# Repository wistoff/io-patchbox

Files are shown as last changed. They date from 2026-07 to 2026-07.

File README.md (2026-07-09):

# I/O Patchbox

A 3-channel sensor-to-actor controller designed for **Manou Wistoff**'s approach to **phygitale Kunsttherapie**, part of her master thesis at [Alanus Kunsthochschule](https://www.alanus.edu).

Building on the concept of phygitale Kunsttherapie, the I/O Patchbox makes the digital tangible by bringing interactive electronics into the physical space. Interactive electronic components become *material* in the art therapy process, just like clay, paint, or fabric. Through process-oriented creating (Tinkering), clients combine classical crafting materials with sensors and actors connected through the I/O Patchbox, resulting in interactive artworks.

The I/O Patchbox is built on an ESP32-S3 Mini with a custom carrier PCB. Each channel auto-detects its sensor type at boot (ultrasonic HC-SR04 or capacitive touch) and drives an output (LED, motor) proportionally via PWM through a low-side NPN transistor stage.

<p align="center">
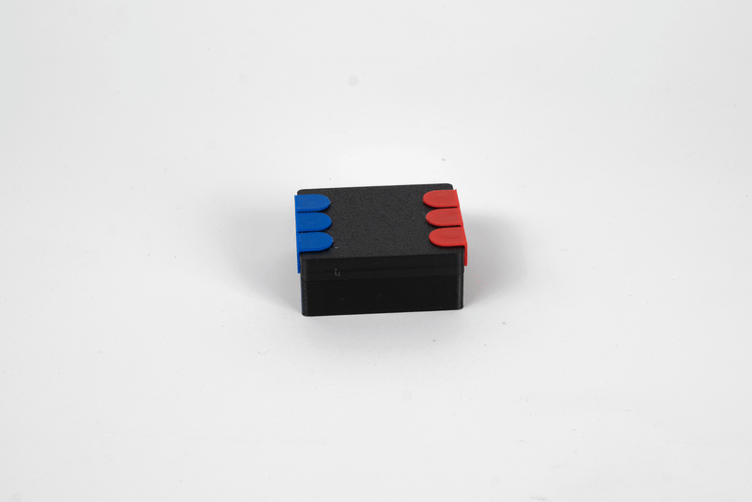
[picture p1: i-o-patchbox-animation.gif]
I/O Patchbox in action
  
</p>

<p align="center">
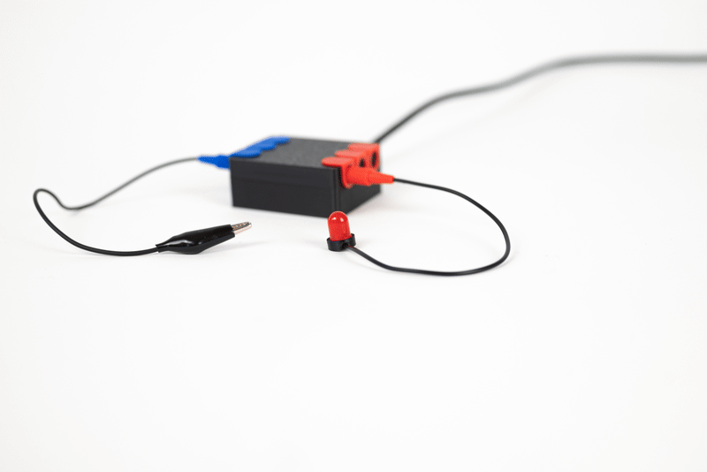
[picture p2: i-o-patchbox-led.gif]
LED output
  
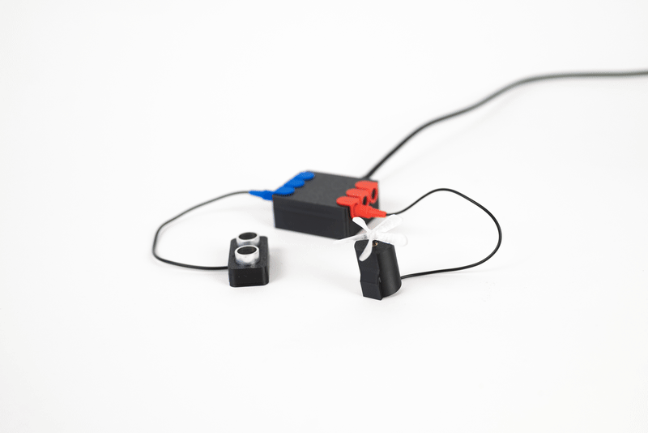
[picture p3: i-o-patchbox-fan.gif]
Fan output
  
</p>

## How it works

- **3 sensor inputs** (TRRS jacks) carrying power, trigger, echo, and ground
- **3 actor outputs** (TRRS jacks) with 5V PWM low-side switch (2N2222 + flyback diode), load adapted in cable
- **Mode switch** to enable/disable all outputs and trigger recalibration
- **Auto-detect** probes each channel for ultrasonic echoes and falls back to touch if none are found
- Ultrasonic: brightness inversely proportional to distance (0-60 cm)
- Touch: brightness proportional to capacitive contact, with adaptive baseline and asymmetric smoothing

## Project structure

```
i-o-patchbox/
├── firmware/
│   ├── esp32s3-mini/            # current target (LOLIN ESP32-S3 Mini)
│   │   ├── src/main.cpp
│   │   ├── platformio.ini
│   │   └── PINOUT.md
│   └── esp32-wroom-dev-board/   # earlier prototype (ESP32 WROOM DevKit)
│       ├── src/main.cpp
│       ├── platformio.ini
│       └── PINOUT.md
├── hardware/                    # KiCad 10 PCB project
│   ├── pcb.kicad_sch             # schematic
│   ├── pcb.kicad_pcb             # board layout (single-sided, home-etched)
│   ├── pcb.kicad_pro             # project file
│   ├── libs/PJ-320A/             # TRRS jack symbol + footprint library
│   ├── gerber/                   # fabrication outputs
│   ├── exports/                  # SVG renders, drill maps
│   ├── backups/                  # KiCad auto-backups
│   └── schaltplan.pdf            # schematic export
└── enclosure/                   # 3D-printable cases (OBJ)
    ├── cable-plug.obj            # cable strain relief (used by all sensors and actors)
    ├── patchbox/                 # main device enclosure
    │   ├── top.obj
    │   ├── bottom.obj
    │   └── indicator.obj
    ├── sensors/                  # sensor housings
    │   ├── ultrasonic-top.obj
    │   └── ultrasonic-bottom.obj
    └── actors/                   # actor housings
        ├── dc-motor-top.obj
        ├── dc-motor-bottom.obj
        ├── vibration-motor-top.obj
        ├── vibration-motor-bottom.obj
        └── led.obj
```

## Pin assignment (ESP32-S3 Mini)

| Channel | Trigger / Touch | Echo  | Actor |
|---|---|---|---|
| 1 | GP1 | GP7 | GP10  |
| 2 | GP2 | GP8 | GP11  |
| 3 | GP3 | GP9 | GP12  |
| Switch  | - | - | GP13  |

## Sensors

All sensors connect via 4-pole TRRS jacks (PJ-320D). Wiring: Tip = +5V, Ring1 = TRIG, Ring2 = ECHO, Sleeve = GND.

Each channel auto-detects its sensor type at startup by probing for ultrasonic echoes. If none are found, it falls back to capacitive touch.

| Type | Part | How it works |
|---|---|---|
| **Ultrasonic** | HC-SR04 | Distance sensor (2-60 cm). All 4 TRRS conductors used. Output brightness is inversely proportional to distance. |
| **Capacitive touch** | Bare wire / crocodile cable | Connects to the ECHO pin (Ring2) only. Touch value increases on contact (ESP32-S3 behavior). Adaptive baseline with asymmetric smoothing. Slow ramp-up absorbs motor-stop noise while fast ramp-down keeps release responsive. Recalibrates each time the switch is toggled on. |

## Actors

All actors connect via TRRS jacks. Wiring: Tip = +5V (always on), Sleeve = transistor collector (PWM-switched ground). Ring1/Ring2 unused.

The board provides a generic 5V PWM low-side driver per channel (2N2222 + 330R base resistor + 1N4007 flyback diode). The load type is adapted in the device cable with a series resistor, so no board changes are needed to swap between LEDs and motors.

| Load | Cable resistor | Notes |
|---|---|---|
| **LED** (red/yellow) | 150R series | ~20 mA at 5V, polarity matters (anode to Tip) |
| **LED** (green/blue/white) | 100R series | Higher Vf, ~18 mA |
| **5V motor** | none | Direct connection, bare cable |
| **3V vibration motor** | none | Runs off 5V directly, no series resistor |

PWM runs at 25 kHz (inaudible for motors), 8-bit resolution (0-255).

## Building firmware

Requires [PlatformIO](https://platformio.org/).

```sh
cd firmware/esp32s3-mini
pio run -t upload
pio device monitor
```

## Hardware

Single-sided carrier PCB designed in KiCad 10 for home etching (toner transfer). All copper on F.Cu, SMD TRRS jacks, THT passives soldered from the top side.

<p align="center">
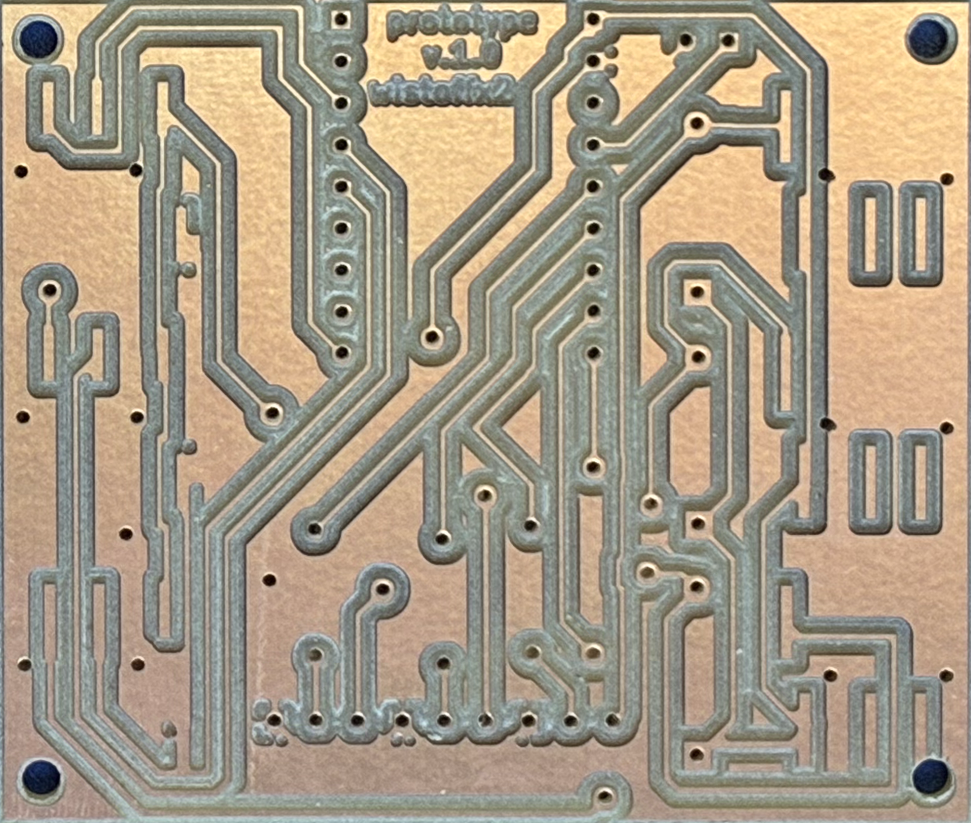
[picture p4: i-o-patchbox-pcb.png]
Etched PCB
  
</p>

Key components: 3x PJ-320D TRRS jacks (sensor), 3x PJ-320D (actor), 3x 2N2222 NPN transistors, 3x 330R base resistors, 3x 1N4007 flyback diodes.

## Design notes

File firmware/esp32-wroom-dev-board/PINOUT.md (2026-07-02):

# ESP32 WROOM DevKit Pinout

```
                          ┌───────────┐
                          │  USB/UART │
                          ├───────────┤
                 3.3V  ──┤           ├──  VIN
                  GND  ──┤           ├──  GND
Sensor 1 TRIG / Touch →  D15  ──┤           ├──  D13
                          D2   ──┤           ├──  D12
Sensor 2 TRIG / Touch →  D4   ──┤           ├──  D14
    Sensor 1 ECHO  →  D16  ──┤           ├──  D27  ← Sensor 3 TRIG / Touch
    Sensor 2 ECHO  →  D17  ──┤           ├──  D26
    Sensor 3 ECHO  →  D5   ──┤           ├──  D25
        Actor 1  →  D18  ──┤           ├──  D33
        Actor 2  →  D19  ──┤           ├──  D32
        Actor 3  →  D21  ──┤           ├──  D35
              D3 (RX)  ──┤           ├──  D34
              D1 (TX)  ──┤           ├──  D39
      Switch →  D22  ──┤           ├──  D36
                  D23  ──┤           ├──  EN
                          └───────────┘
```

## Channel Assignment

| | Sensor | Sensor | Actor  |
|---|---|---|---|
| | TRIG / Touch | ECHO | LED |
| **1** | D15 (GPIO 15)| D16 | D18 |
| **2** | D4  (GPIO 4) | D17 | D19 |
| **3** | D27 (GPIO 27)| D5 | D21 |

## Wiring per Channel

### Ultrasonic (HC-SR04)
```
HC-SR04 VCC  → 5V
HC-SR04 GND  → GND
HC-SR04 TRIG → TRIG pin
HC-SR04 ECHO → ECHO pin
```

### Touch (wire/cable)
```
Wire → TRIG pin (no other connections needed)
```

Each channel auto-detects the sensor type at boot.
LED anode → LED pin (with resistor), cathode → GND.

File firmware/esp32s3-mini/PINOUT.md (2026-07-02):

# ESP32-S3 Mini Pinout

```
                        ┌───────────┐
                        │  USB-C    │
                        ├───────────┤
                  5V  ──┤           ├──  TX
                 GND  ──┤           ├──  RX
            3V3(OUT)  ──┤           ├──  GP13 ← Switch
Sensor 1 TRIG/Touch → GP1  ──┤           ├──  GP12 ← Actor 3
Sensor 2 TRIG/Touch → GP2  ──┤           ├──  GP11 ← Actor 2
Sensor 3 TRIG/Touch → GP3  ──┤           ├──  GP10 ← Actor 1
                 GP4  ──┤           ├──  GP9  ← Sensor 3 ECHO
                 GP5  ──┤           ├──  GP8  ← Sensor 2 ECHO
                 GP6  ──┤           ├──  GP7  ← Sensor 1 ECHO
                        │           ├──  GP16
                        │           ├──  GP15
                        │           ├──  GP14
                        └───────────┘
```

## Channel Assignment

| | Sensor | Sensor | Actor  |
|---|---|---|---|
| | TRIG / Touch | ECHO | LED |
| **1** | GP1 | GP7 | GP10 |
| **2** | GP2 | GP8 | GP11 |
| **3** | GP3 | GP9 | GP12 |
| **Switch** | - | - | GP13 |

## Wiring per Channel

### Ultrasonic (HC-SR04)
```
HC-SR04 VCC  → 5V
HC-SR04 GND  → GND
HC-SR04 TRIG → TRIG pin
HC-SR04 ECHO → ECHO pin
```

### Touch (wire/cable)
```
Wire → TRIG pin (no other connections needed)
```

### Switch
```
Toggle switch between GP13 and GND
```

Each channel auto-detects the sensor type at boot.
LED anode → LED pin (with resistor), cathode → GND.

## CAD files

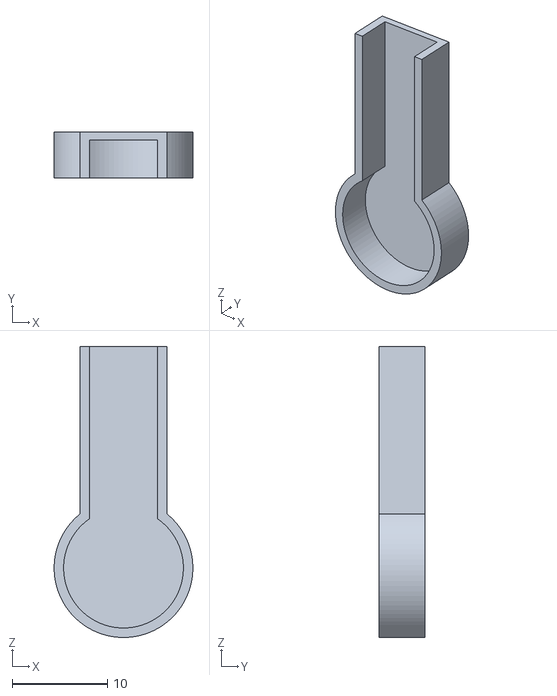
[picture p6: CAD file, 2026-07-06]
enclosure/actors/vibration-motor-top.obj
14.6 x 4.80 x 30.6

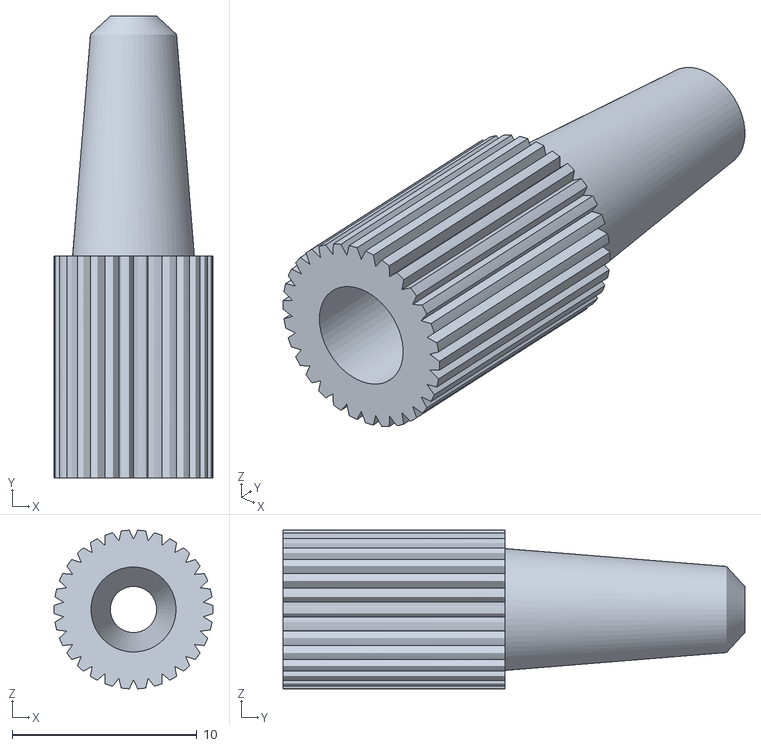
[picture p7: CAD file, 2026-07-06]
enclosure/cable-plug.obj
8.60 x 25.0 x 8.59

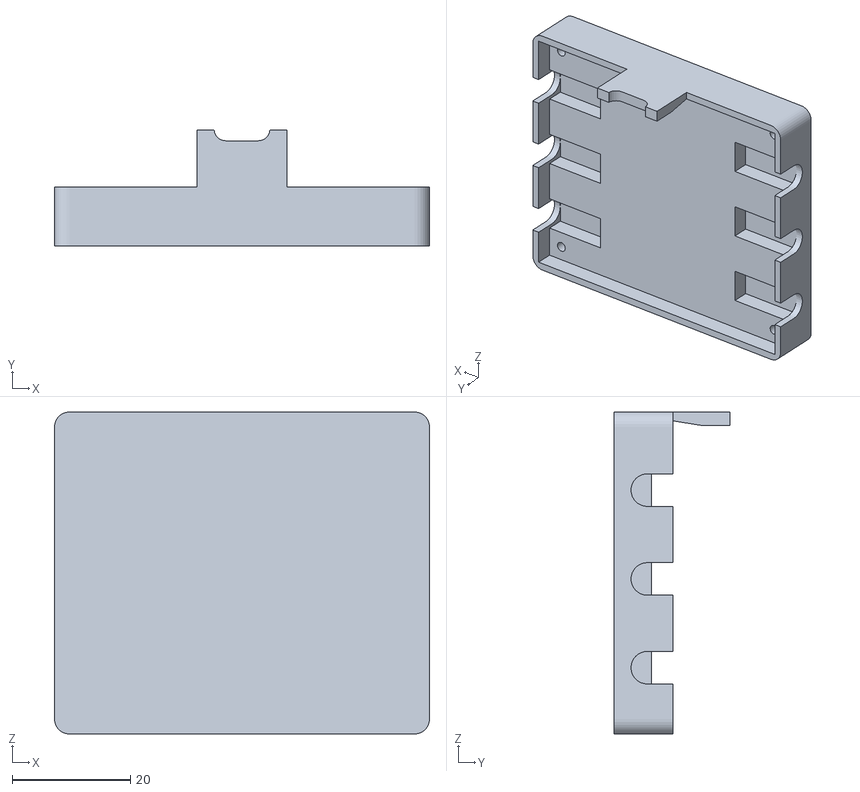
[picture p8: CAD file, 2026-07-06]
enclosure/patchbox/bottom.obj
63.4 x 19.6 x 54.4

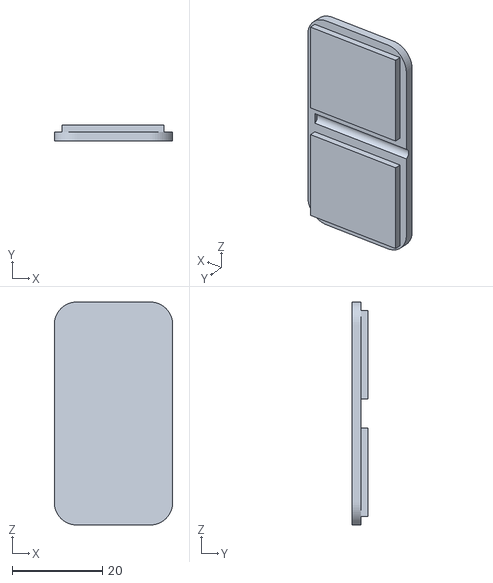
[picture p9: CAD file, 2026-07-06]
enclosure/sensors/ultrasonic-bottom.obj
26.3 x 3.50 x 49.5

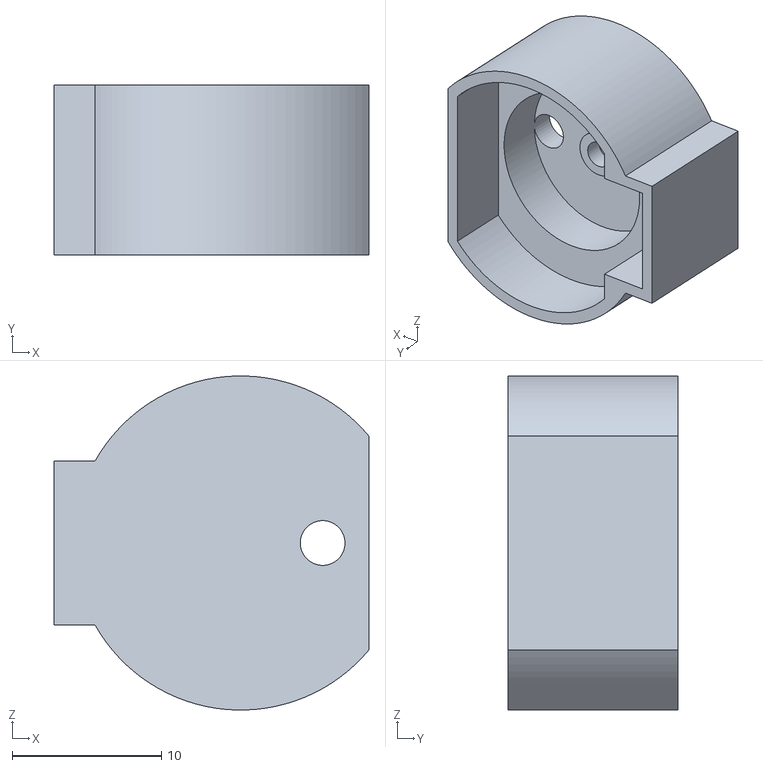
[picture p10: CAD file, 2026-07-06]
enclosure/actors/dc-motor-top.obj
21.1 x 11.4 x 22.4

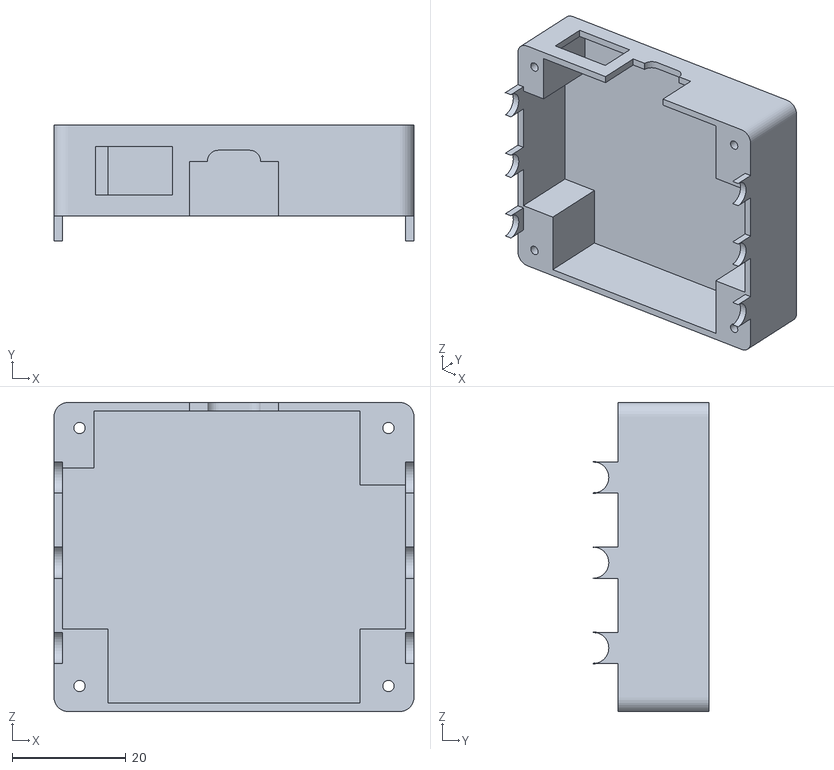
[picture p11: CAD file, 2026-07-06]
enclosure/patchbox/top.obj
63.4 x 20.4 x 54.4

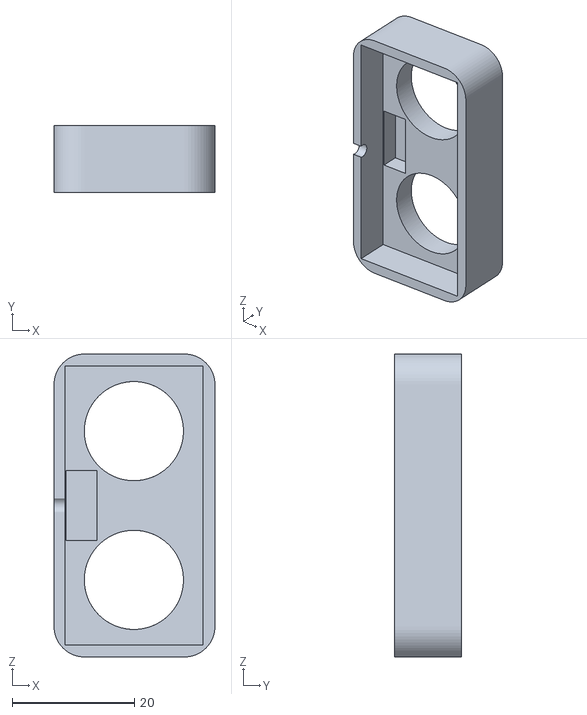
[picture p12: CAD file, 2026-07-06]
enclosure/sensors/ultrasonic-top.obj
26.3 x 11.0 x 49.5

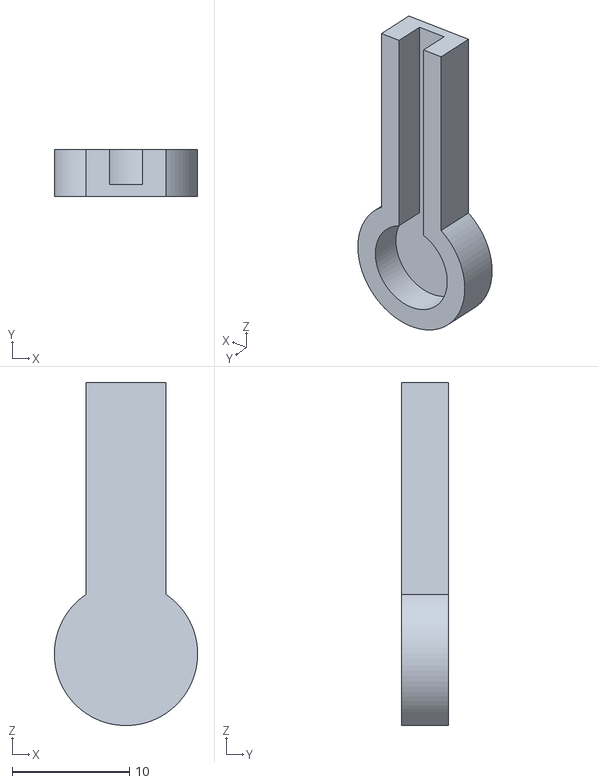
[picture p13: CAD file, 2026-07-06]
enclosure/actors/vibration-motor-bottom.obj
12.2 x 4.00 x 29.2

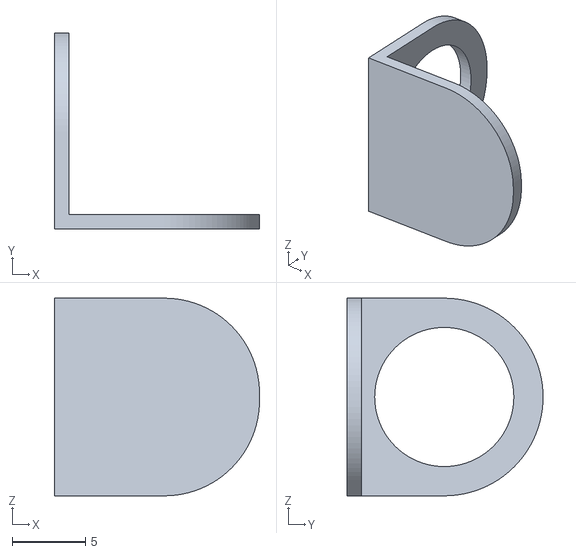
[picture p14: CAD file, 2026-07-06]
enclosure/patchbox/indicator.obj
14.0 x 13.4 x 13.5

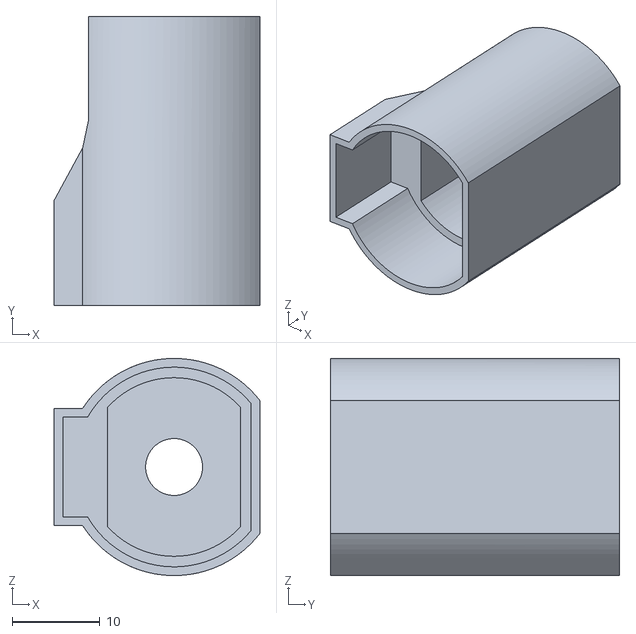
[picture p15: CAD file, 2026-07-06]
enclosure/actors/dc-motor-bottom.obj
23.5 x 33.0 x 24.8

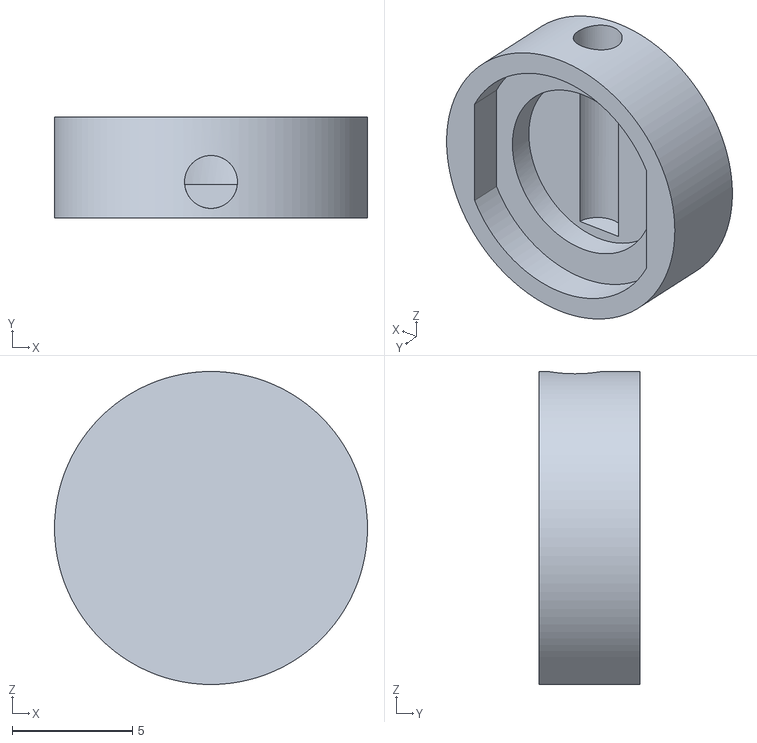
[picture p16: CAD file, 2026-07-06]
enclosure/actors/led.obj
13.0 x 4.20 x 13.0

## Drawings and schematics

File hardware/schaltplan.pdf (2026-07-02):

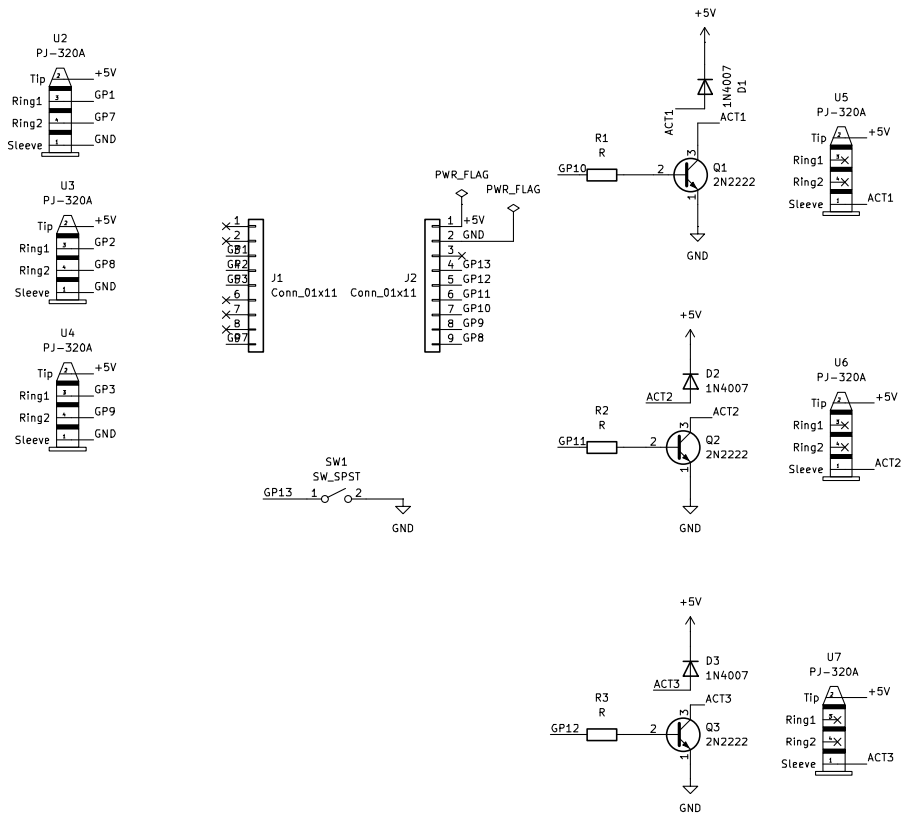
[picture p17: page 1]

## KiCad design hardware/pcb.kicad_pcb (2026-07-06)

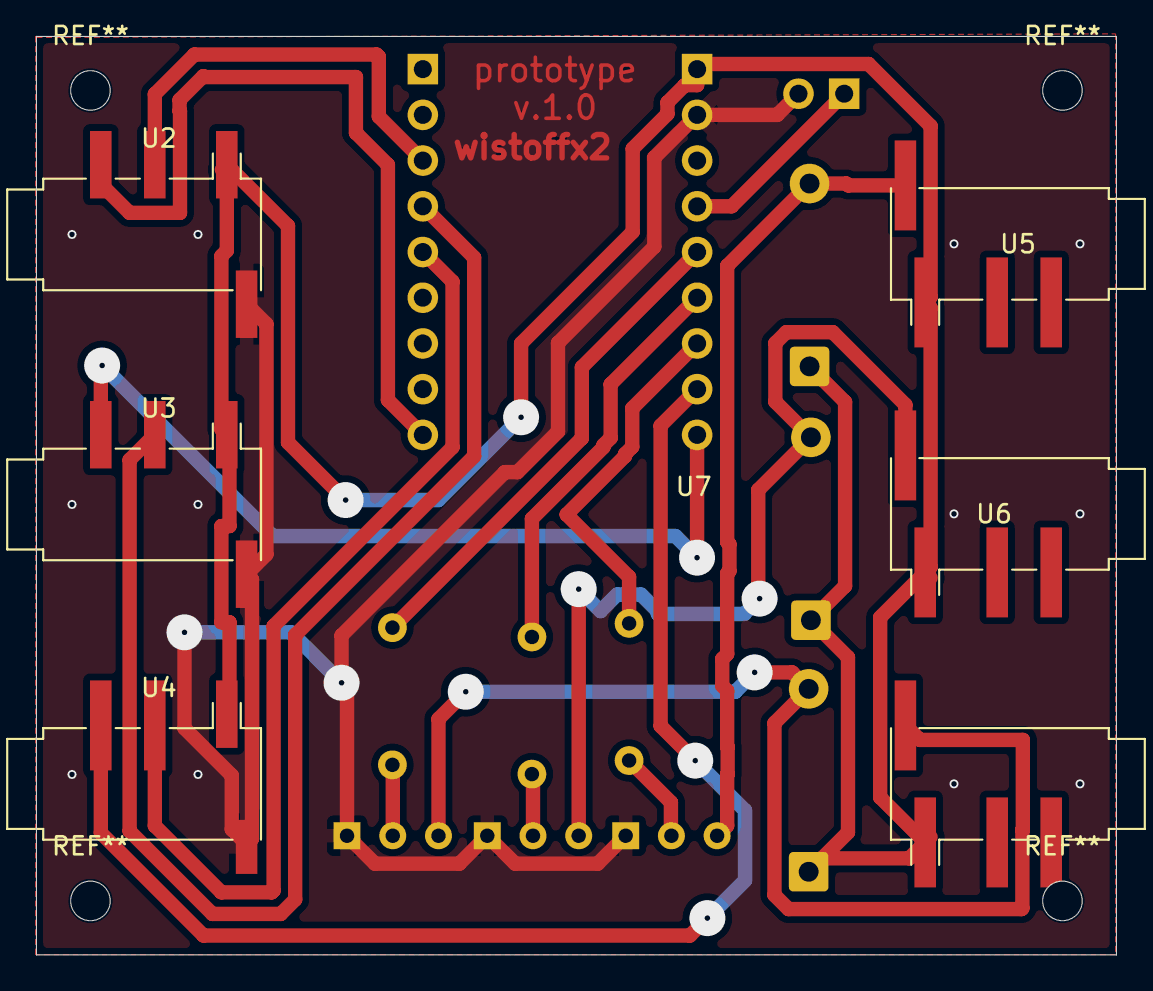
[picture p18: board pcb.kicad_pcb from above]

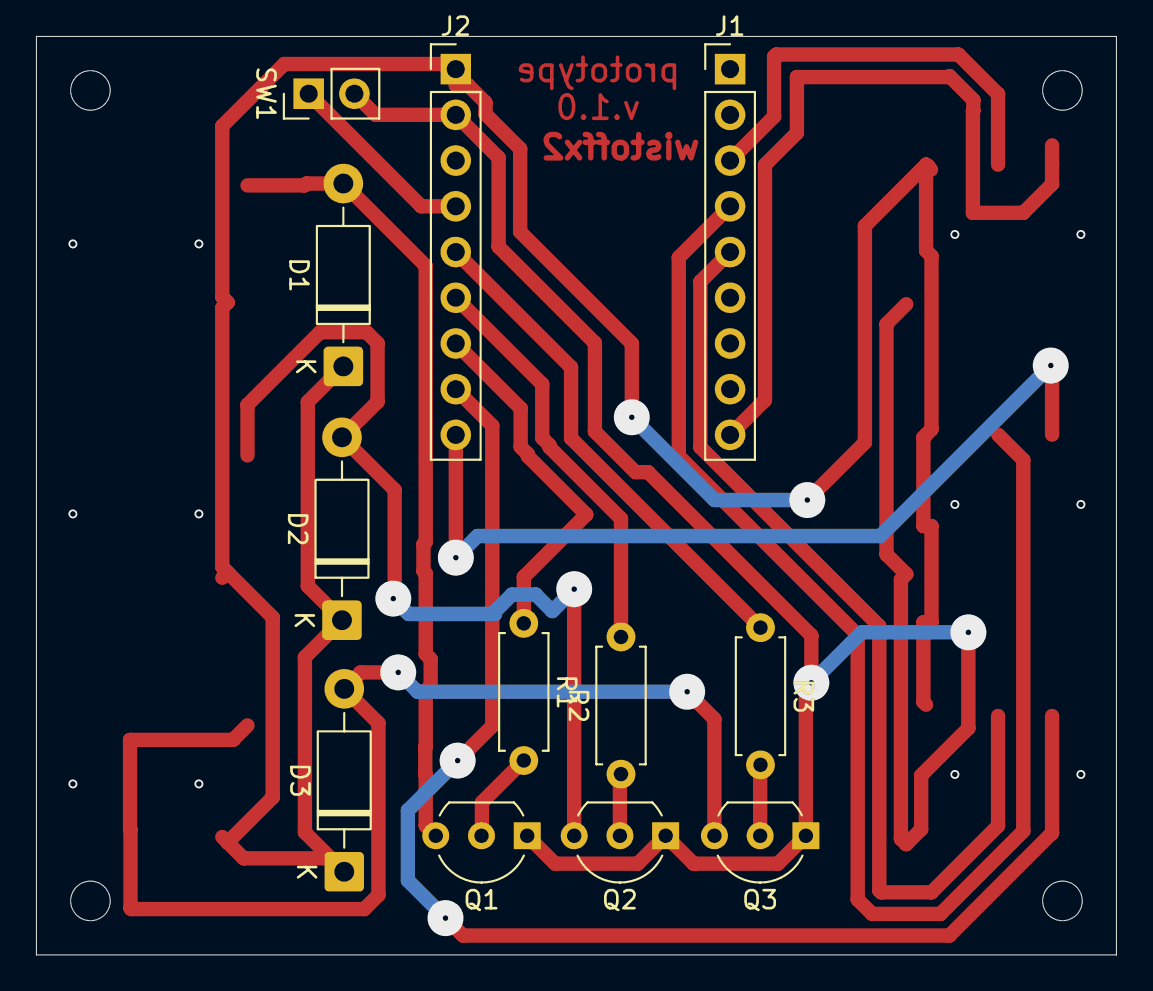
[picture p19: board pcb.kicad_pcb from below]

Board: 2 copper layers, 60.0 x 51.0 mm, 18 parts (12 on the bottom side), 2 nets.

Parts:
D1, D2, D3: 1N4007; D_DO-41_SOD81_P10.16mm_Horizontal
J1, J2: Conn_01x11; PinHeader_1x09_P2.54mm_Vertical
Q1, Q2, Q3: 2N2222; TO-92_Inline_Wide
R1, R2, R3: R; R_Axial_DIN0207_L6.3mm_D2.5mm_P7.62mm_Horizontal
SW1: SW_SPST; PinHeader_1x02_P2.54mm_Vertical
U2, U3, U4, U5, U6, U7: PJ-320A; PJ-320D_SMD_remap

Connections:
+5V: U2.2 (Tip), U3.2 (Tip), U4.2 (Tip), U5.2 (Tip), U6.2 (Tip), U7.2 (Tip)
GND: U2.1 (Sleeve), U3.1 (Sleeve), U4.1 (Sleeve)

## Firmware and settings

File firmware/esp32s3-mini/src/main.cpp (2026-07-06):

#include <Arduino.h>

// Pinout (ESP32-S3 Mini)
// Sensor jack (TRRS): Tip=+5V, Ring1=TRIG, Ring2=ECHO, Sleeve=GND
// Actor jack (TRRS):  Tip=+5V, Sleeve=OUT-, Ring1/Ring2=unused
// Touch connects to ECHO pin (Ring2) via crocodile cable

const int SWITCH_PIN = 13;
const int NUM_CH = 3;
const int TRIG[] = {1, 2, 3};
const int ECHO[] = {7, 8, 9};
const int ACT[]  = {10, 11, 12};

const float MAX_DIST = 60.0;
const int CALIB_SKIP = 10;
const int CALIB_SAMPLES = 40;

bool isTouch[NUM_CH];
int baseline[NUM_CH];
int calibCount[NUM_CH];
float smoothed[NUM_CH];
bool active = false;

float readDist(int ch) {
  digitalWrite(TRIG[ch], LOW);
  delayMicroseconds(2);
  digitalWrite(TRIG[ch], HIGH);
  delayMicroseconds(10);
  digitalWrite(TRIG[ch], LOW);
  return pulseIn(ECHO[ch], HIGH, 30000) * 0.0343 / 2.0;
}

bool detectUltrasonic(int ch) {
  pinMode(TRIG[ch], OUTPUT);
  pinMode(ECHO[ch], INPUT);
  delay(100);
  int hits = 0;
  for (int i = 0; i < 5; i++) {
    float d = readDist(ch);
    Serial.printf("CH%d probe %d: %.1f cm\n", ch, i, d);
    if (d >= 2.0 && d <= 400.0) hits++;
    delay(50);
  }
  return hits >= 3;
}

void blinkAll(int times) {
  for (int i = 0; i < times; i++) {
    for (int ch = 0; ch < NUM_CH; ch++) ledcWrite(ACT[ch], 255);
    delay(150);
    for (int ch = 0; ch < NUM_CH; ch++) ledcWrite(ACT[ch], 0);
    delay(150);
  }
}

void detectAndCalibrate() {
  for (int ch = 0; ch < NUM_CH; ch++) {
    isTouch[ch] = !detectUltrasonic(ch);
    if (isTouch[ch]) pinMode(ECHO[ch], INPUT);
    baseline[ch] = 0;
    calibCount[ch] = 0;
    smoothed[ch] = 0;
    Serial.printf("CH%d: %s\n", ch, isTouch[ch] ? "Touch" : "Ultrasonic");
  }
}

void setup() {
  Serial.begin(115200);
  delay(2000);
  pinMode(SWITCH_PIN, INPUT_PULLUP);
  for (int ch = 0; ch < NUM_CH; ch++)
    ledcAttach(ACT[ch], 25000, 8);
  Serial.println("MANOU ready");
}

void loop() {
  bool switchOn = digitalRead(SWITCH_PIN) == LOW;

  if (switchOn && !active) {
    active = true;
    Serial.println("Switch: ON");
    detectAndCalibrate();
    blinkAll(5);
  } else if (!switchOn && active) {
    active = false;
    Serial.println("Switch: OFF");
    for (int ch = 0; ch < NUM_CH; ch++) ledcWrite(ACT[ch], 0);
  }

  if (!active) { delay(50); return; }

  for (int ch = 0; ch < NUM_CH; ch++) {
    int bright = 0;

    if (isTouch[ch]) {
      int val = touchRead(ECHO[ch]);

      // Calibration: skip warmup, then take min of samples
      if (calibCount[ch] < CALIB_SKIP + CALIB_SAMPLES) {
        calibCount[ch]++;
        if (calibCount[ch] > CALIB_SKIP && (baseline[ch] == 0 || val < baseline[ch]))
          baseline[ch] = val;
        if (calibCount[ch] == CALIB_SKIP + CALIB_SAMPLES)
          Serial.printf("CH%d: baseline=%d\n", ch, baseline[ch]);
        ledcWrite(ACT[ch], 0);
        continue;
      }

      int rise = val - baseline[ch];
      int deadzone = baseline[ch] / 5;

      // Drift baseline when idle
      if (rise < deadzone)
        baseline[ch] += (val - baseline[ch]) / 10;

      if (rise > deadzone)
        bright = constrain(map(rise, deadzone, baseline[ch], 0, 255), 0, 255);

      // Asymmetric smoothing: fast rise, faster fall
      float alpha = (bright > smoothed[ch]) ? 0.5 : 0.7;
      smoothed[ch] += alpha * (bright - smoothed[ch]);
      bright = (int)(smoothed[ch] + 0.5);
    } else {
      float dist = readDist(ch);
      if (dist > 0 && dist <= MAX_DIST)
        bright = 255 - (int)(dist / MAX_DIST * 255);

      smoothed[ch] += 0.6 * (bright - smoothed[ch]);
      bright = (int)(smoothed[ch] + 0.5);
      if (bright < 20) bright = 0;
    }

    ledcWrite(ACT[ch], bright);
  }

  delay(20);
}

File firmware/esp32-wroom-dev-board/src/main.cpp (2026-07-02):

#include <Arduino.h>

// --- PINOUT ---
// Channel 0: TRIG=D15 (Touch3), ECHO=D16, LED=D18
// Channel 1: TRIG=D4  (Touch0), ECHO=D17, LED=D19
// Channel 2: TRIG=D27 (Touch7), ECHO=D5,  LED=D21

const int SWITCH_PIN = 22;
const int NUM_CHANNELS = 3;

const int TRIG_PINS[NUM_CHANNELS] = {15, 4, 27};  // Touch3, Touch0, Touch7 (D27 on VIN side)
const int ECHO_PINS[NUM_CHANNELS] = {16, 17, 5};
const int LED_PINS[NUM_CHANNELS]  = {18, 19, 21};

const int PWM_FREQ = 5000;
const int PWM_RES = 8;

const float MAX_DIST_CM = 60.0;

bool useTouch[NUM_CHANNELS] = {false, false, false};
int touchBaseline[NUM_CHANNELS] = {0, 0, 0};
bool active = false;

float readDistanceCm(int ch) {
  digitalWrite(TRIG_PINS[ch], LOW);
  delayMicroseconds(2);
  digitalWrite(TRIG_PINS[ch], HIGH);
  delayMicroseconds(10);
  digitalWrite(TRIG_PINS[ch], LOW);
  long duration = pulseIn(ECHO_PINS[ch], HIGH, 30000);
  return duration * 0.0343 / 2.0;
}

bool detectUltrasonic(int ch) {
  pinMode(TRIG_PINS[ch], OUTPUT);
  pinMode(ECHO_PINS[ch], INPUT);
  for (int i = 0; i < 5; i++) {
    if (readDistanceCm(ch) > 0) return true;
    delay(50);
  }
  return false;
}

void blinkAll(int times) {
  for (int i = 0; i < times; i++) {
    for (int ch = 0; ch < NUM_CHANNELS; ch++) ledcWrite(LED_PINS[ch], 255);
    delay(150);
    for (int ch = 0; ch < NUM_CHANNELS; ch++) ledcWrite(LED_PINS[ch], 0);
    delay(150);
  }
}

void setup() {
  Serial.begin(115200);
  pinMode(SWITCH_PIN, INPUT_PULLUP);

  for (int ch = 0; ch < NUM_CHANNELS; ch++) {
    ledcAttach(LED_PINS[ch], PWM_FREQ, PWM_RES);

    if (detectUltrasonic(ch)) {
      useTouch[ch] = false;
      Serial.printf("CH%d: Ultrasonic (TRIG=%d, ECHO=%d, LED=%d)\n",
                     ch, TRIG_PINS[ch], ECHO_PINS[ch], LED_PINS[ch]);
    } else {
      useTouch[ch] = true;
      pinMode(TRIG_PINS[ch], INPUT);
      int sum = 0;
      for (int i = 0; i < 10; i++) {
        sum += touchRead(TRIG_PINS[ch]);
        delay(20);
      }
      touchBaseline[ch] = sum / 10;
      Serial.printf("CH%d: Touch (GPIO %d, baseline=%d, LED=%d)\n",
                     ch, TRIG_PINS[ch], touchBaseline[ch], LED_PINS[ch]);
    }
  }
}

void loop() {
  bool switchOn = digitalRead(SWITCH_PIN) == LOW;

  if (switchOn && !active) {
    active = true;
    Serial.println("Switch: ON");
    blinkAll(5);
  } else if (!switchOn && active) {
    active = false;
    Serial.println("Switch: OFF");
    for (int ch = 0; ch < NUM_CHANNELS; ch++) ledcWrite(LED_PINS[ch], 0);
  }

  if (!active) {
    delay(50);
    return;
  }

  for (int ch = 0; ch < NUM_CHANNELS; ch++) {
    int brightness = 0;

    if (useTouch[ch]) {
      int val = touchRead(TRIG_PINS[ch]);
      int drop = touchBaseline[ch] - val;
      if (drop > 0) {
        brightness = map(drop, 0, touchBaseline[ch] / 2, 0, 255);
        brightness = constrain(brightness, 0, 255);
      }
      Serial.printf("CH%d TOUCH: pin=%d val=%d base=%d drop=%d bright=%d\n",
                     ch, TRIG_PINS[ch], val, touchBaseline[ch], drop, brightness);
    } else {
      float dist = readDistanceCm(ch);
      if (dist > 0 && dist <= MAX_DIST_CM) {
        brightness = 255 - (int)(dist / MAX_DIST_CM * 255);
      }
      Serial.printf("CH%d ULTRA: pin=%d dist=%.1f bright=%d\n",
                     ch, TRIG_PINS[ch], dist, brightness);
    }

    ledcWrite(LED_PINS[ch], brightness);
  }

  delay(100);
}

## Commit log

2026-07-06 content update
    [pcb.kicad_pcb]
2026-07-06 added 3d print files
    [bottom.obj, cable-plug.obj, dc-motor-bottom.obj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]
2026-07-06 added pcb photo
